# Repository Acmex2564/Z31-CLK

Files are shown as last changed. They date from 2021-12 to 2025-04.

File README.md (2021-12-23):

# Z31-CLK
Replacement clock for Z31

Z31 GL clocks are a a 4-digit VFD driven by a HD44013 MCU. 

For no good reason I intend to replace all parts except the VFD, which uniquely operates directly DC voltage through a couple current limiting resistors and protection diodes. 

Replacement clock will source time from a new TCU design, and communicate over CAN, allowing it to serve as an interface to other accessories I've installed.

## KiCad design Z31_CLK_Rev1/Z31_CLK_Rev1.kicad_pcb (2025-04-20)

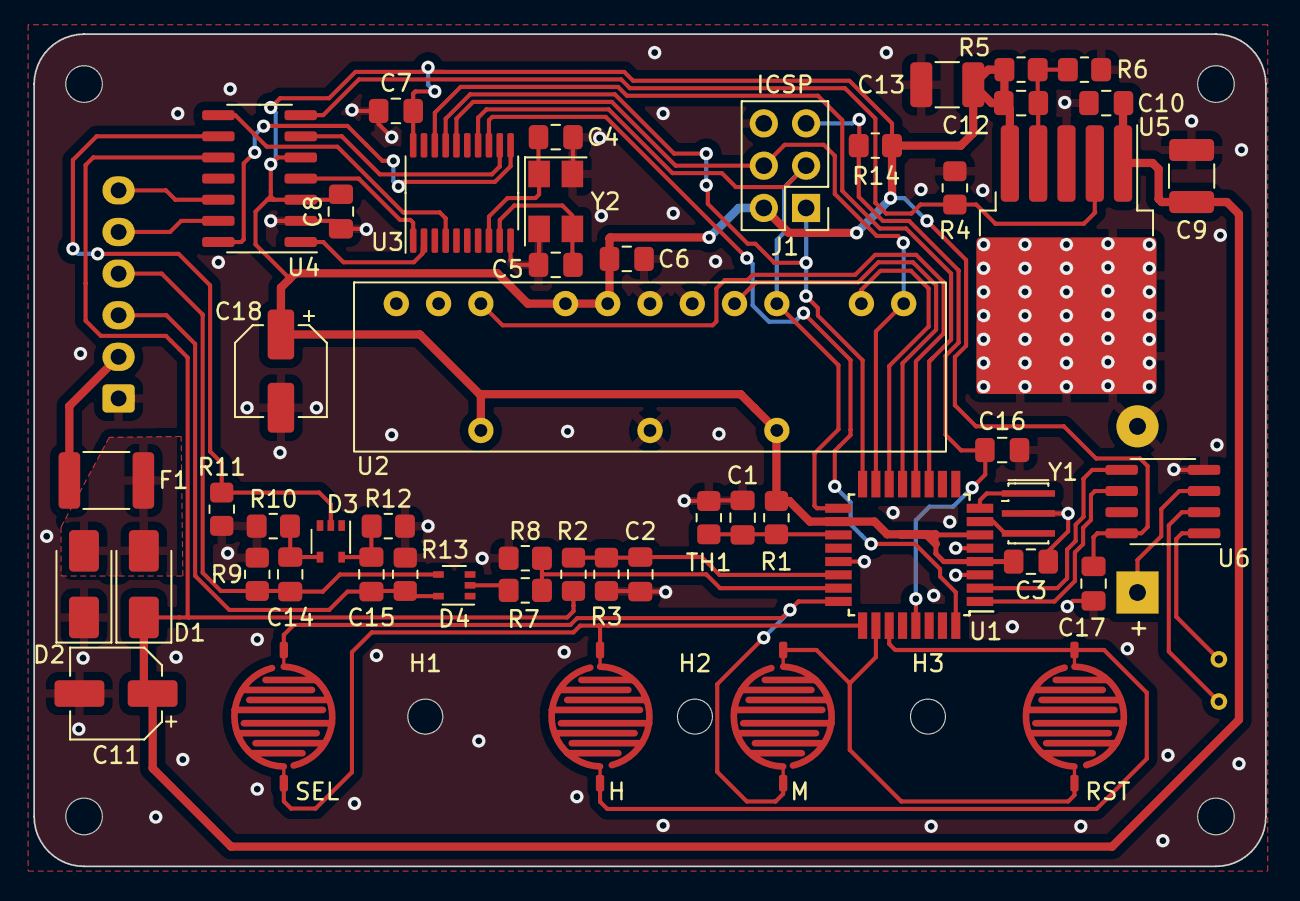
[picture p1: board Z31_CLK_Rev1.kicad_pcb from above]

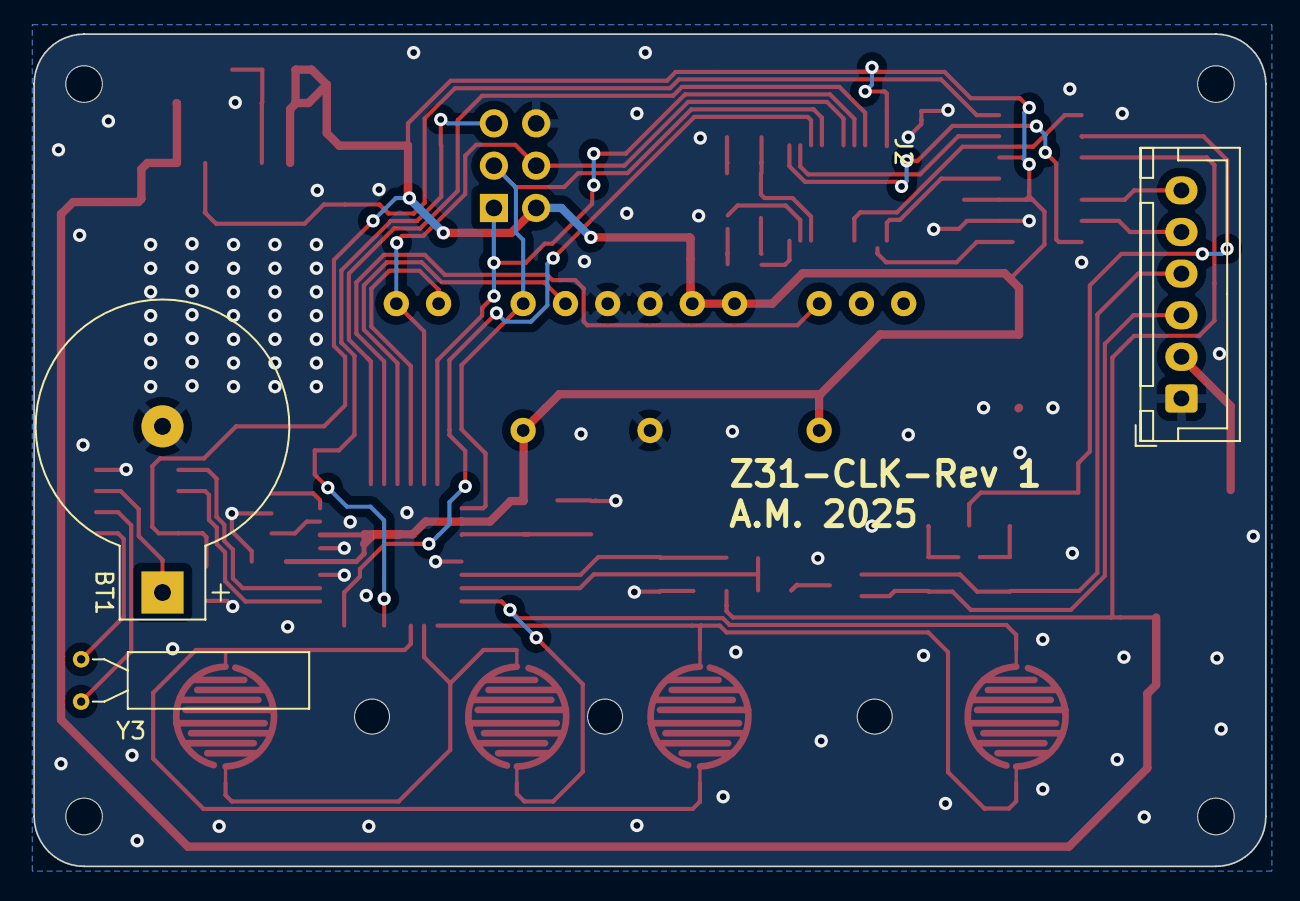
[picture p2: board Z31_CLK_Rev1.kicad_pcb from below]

Board: 2 copper layers, 74.0 x 50.0 mm, 61 parts (3 on the bottom side), 45 nets.

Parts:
BT1: 3V; BatteryHolder_Keystone_500
C1, C2, C6, C7, C8, C10, C16, C17: 100nF; C_0805_2012Metric_Pad1.18x1.45mm_HandSolder
C3, C14, C15: 100n; C_0805_2012Metric_Pad1.18x1.45mm_HandSolder
C4, C5: 10pF; C_0805_2012Metric_Pad1.18x1.45mm_HandSolder
C9: 1u; C_1210_3225Metric_Pad1.33x2.70mm_HandSolder
C11, C18: 22uF; CP_Elec_5x5.7
C12: N/A; C_0805_2012Metric_Pad1.18x1.45mm_HandSolder
C13: yes; C_1210_3225Metric_Pad1.33x2.70mm_HandSolder
D1: D_Schottky; D_SMA
D2: SMAJ18CAQ-13-F; D_SMA
D3, D4: MMBD4448HCQW; SOT-353_SC-70-5
F1: Polyfuse; Fuse_1812_4532Metric_Pad1.30x3.40mm_HandSolder
H1, H2, H3: MountingHole; MountingHole_2.1mm
H4, H5, H6, H7: MountingHole; MountingHole_2.2mm_M2_DIN965
J1: ICSP; PinHeader_2x03_P2.54mm_Vertical
J2: Conn_01x06_Male; JST_XH_B6B-XH-A_1x06_P2.50mm_Vertical
R1: 47K; R_0805_2012Metric_Pad1.20x1.40mm_HandSolder
R2, R3: R; R_0805_2012Metric_Pad1.20x1.40mm_HandSolder
R4, R7, R8, R9, R10, R11, R12, R13, R14: 10k; R_0805_2012Metric_Pad1.20x1.40mm_HandSolder
R5, R6: N/A; R_0805_2012Metric_Pad1.20x1.40mm_HandSolder
SW1: Select; membrane_button
SW2: Hour; membrane_button
SW3: Reset; membrane_button
SW4: Minute; membrane_button
TH1: NTC 47K; R_0805_2012Metric_Pad1.20x1.40mm_HandSolder
U1: ATMEGA328-AURCT-ND; TQFP-32_7x7mm_P0.8mm
U2: HCMS-291x
U3: MCP2515-xST; TSSOP-20_4.4x6.5mm_P0.65mm
U4: TJR1443; SO-14_3.9x8.65mm_P1.27mm
U5: NCV4276B; TO-263-5_TabPin3
U6: DS1307Z+; SOIC-8_3.9x4.9mm_P1.27mm
Y1: 16MHz; Resonator_SMD_Murata_CSTxExxV-3Pin_3.0x1.1mm_HandSoldering
Y2: 8MHz; Crystal_SMD_5032-4Pin_5.0x3.2mm
Y3: 32.768k; Crystal_AT310_D3.0mm_L10.0mm_Horizontal

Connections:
+5V: C3.1, C6.2, C7.2, C8.2, C12.1, C13.1, C17.2, C18.1, J1.2, R1.1, R5.1, R14.1, U1.4 (VCC), U1.6 (VCC), U1.18 (AVCC), U2.3 (V_{LED}), U2.10 (V_{LED}), U2.21 (SEL), U2.22 (V_{Logic}), U3.20 (VDD), U4.3 (Vcc), U4.5 (Vio), U5.5 (OUT), U6.8 (VCC)
+12V: C9.1, C10.1, C11.1, D1.1 (K), R2.1, U4.10 (Vbat), U5.1 (IN)
/+12V_ACC: C14.1, D4.4 (A), J2.4, R9.1
/+12V_CONST: F1.2, J2.2
/CANH: J2.5, U4.13 (CANH)
/CANL: J2.6, U4.12 (CANL)
/CAN_EN: U3.12 (~RX0BF), U4.6 (EN)
/CAN_ERR: U3.4 (~TX0RTS), U4.8 (~ERR)
/CAN_STB: U3.11 (~RX1BF), U4.14 (~STB_N)
/ILLUM: C15.1, D4.5 (A), J2.3, R13.1
/Key_1: SW3.2, SW4.2, U1.26 (PC3)
/Key_2: SW1.1, SW2.1, U1.25 (PC2)
/Key_A: SW1.2, SW3.1, U1.24 (PC1)
/Key_B: SW2.2, SW4.1, U1.27 (PC4)
/MODULE_TEMPERATURE: C1.1, R1.2, TH1.1, U1.19 (ADC6)
/MODULE_VOLTAGE: C2.1, R2.2, R3.1, U1.22 (ADC7)
/RS_DISP: U1.14 (PB2), U2.15 (RS)
/RXCAN: U3.2 (RXCAN), U4.1 (TXCAN)
/TXCAN: U3.1 (TXCAN), U4.4 (RXCAN)
/Wake_Pulse: D3.2 (K), R11.1, U4.9 (WAKE)
/Wake_Sense: R7.2, R8.1, U1.23 (PC0)
/~CS_CAN: U1.11 (PD7), U3.18 (~CS)
/~CS_DISP: U1.13 (PB1), U2.18 (~CE)
/~INH: R4.1, U4.7 (INH), U5.2 (INH)
/~RST_DISP: U1.12 (PB0), U2.24 (~RESET)
CAN_INT: U1.32 (PD2), U3.13 (~INT)
GND: BT1.2 (-), C1.2, C2.2, C3.2, C4.1, C5.1, C6.1, C7.1, C8.1, C9.2, C10.2, C11.2, C13.2, C16.1, C17.1, C18.2, D2.1 (A1), J1.6, J2.1, R3.2, R4.2, R6.2, R8.2, R9.2, R10.2, R11.2, R12.2, R13.2, TH1.2, U1.3 (GND), U1.5 (GND), U1.21 (GND), U2.7 (GND_{LED}), U2.19 (BLANK), U2.20 (GND_{Logic}), U3.10 (VSS), U4.2 (GND), U5.3 (GND), U6.4 (GND), Y1.2, Y2.2, Y2.4
MISO: J1.1, U1.16 (PB4), U3.17 (SO)
MOSI: J1.4, U1.15 (PB3), U2.14 (Data_In), U3.16 (SI)
unnamed: BT1.1 (+), U6.3 (VBAT)
unnamed: D1.2 (A), D2.2 (A2), F1.1
unnamed: C14.2, D3.4 (A), R10.1
unnamed: C15.2, D3.5 (A), R12.1
unnamed: D4.2 (K), R7.1
unnamed: U1.1 (PD3), U6.6 (SCL)
unnamed: U1.2 (PD4), U6.5 (SDA)
unnamed: U1.7 (XTAL1/PB6), Y1.3
unnamed: U1.8 (XTAL2/PB7), Y1.1
unnamed: C5.2, U3.9 (OSC1), Y2.3
unnamed: C4.2, U3.8 (OSC2), Y2.1
unnamed: C12.2, R5.2, R6.1, U5.4 (VA)
unnamed: U6.1 (X1), Y3.2
unnamed: U6.2 (X2), Y3.1
RESET: C16.2, J1.5, R14.2, U1.29 (~RESET/PC6)
SCK: J1.3, U1.17 (PB5), U2.17 (CLK), U3.14 (SCK)

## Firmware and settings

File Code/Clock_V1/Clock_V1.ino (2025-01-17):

#include <LedDisplay.h>
#include <Keypad.h>
#include <TimeLib.h>
#include <ACAN.h>

#define CAN_TX 3
#define CAN_RX 4
#define CAN_EN 1

#define CAN_BITRATE_HS 5*100*1000 //500kbit/s
#define ID_LAMBDA 0x400
#define ID_BRIGHTNESS 0x202
#define ID_TEMPERATURE 0x750
#define ID_STATUS 0x755
#define ID_SPEED 0x760
#define ID_FUEL 0x720

#define ledData 23
#define ledRS 22
#define ledClk 21
#define ledEn 15
#define ledRst 14

#define ledLen 8

#define TIME_HEADER  "T"   // Header tag for serial time sync message

#define PAGE_CLOCK 0 //"HH:MM:SS"
#define PAGE_CAL 1 //"DD/MM/YY"
#define PAGE_AFR 2 //"AFR XXXX"
#define PAGE_LSU_TEMP 3 //"LSU YYYC"
#define PAGE_LSU_STATE 4 //"STA 0xZZ"
#define PAGE_RAD_TEMP 5 //"RAD YY*C"
#define PAGE_FAN_SPD 6 //"FAN XXX%"
#define PAGE_FUEL_AP 7 //
#define PAGE_MAN_AP 8 //
#define PAGE_VEH_SPD 9 //
#define PAGE_FUEL_1 10 //
#define PAGE_FUEL_2 11 //



const byte rows = 2;
const byte cols = 2;

char buttons[rows][cols] = {
  {'S', 'R'},
  {'+', '-'}
};
byte rowPins[rows] = {5, 6};
byte colPins[cols] = {7, 8};

Keypad buttonPad = Keypad(makeKeymap(buttons), rowPins, colPins, rows, cols);

LedDisplay disp = LedDisplay(ledData, ledRS, ledClk, ledEn, ledRst, ledLen);

int brightness = 15;

int currentPage = 0;

int TZ_ADJUST = -4;


uint8_t currentSecond = second();

word lambda;
float afr;
unsigned int temp = 0;
byte lsu_stat;

int tempWater;
int tempAmbient;
int pressManifold;
int pressFuel;
int vehicleSpeed;
int pwmFan;
int fuelMain;
int fuelSub;


unsigned long timeLastLambda;
unsigned long timeLastTemp;
unsigned long timeLastStatus;
unsigned long timeLastSpeed;
unsigned long timeLastFuel;
unsigned long timeMaxMessage = 2000;

void setup() {
  // put your setup code here, to run once:
  Serial.begin(115200);
  //while (!Serial);
  disp.begin();
  disp.setBrightness(brightness);

  pinMode(CAN_TX, OUTPUT);
  pinMode(CAN_EN, OUTPUT);
  pinMode(CAN_RX, INPUT_PULLUP);

  ACANSettings settingsHSCan (CAN_BITRATE_HS);


  settingsHSCan.mRxPinHasInternalPullUp = false;
  settingsHSCan.mTxPinIsOpenCollector = false;
  uint32_t errorCan = ACAN::can0.begin(settingsHSCan);

  if (0 == errorCan) {
    Serial.print("Alive. CAN OK");
  }
  else {
    disp.print("ERR 0x"); disp.print(errorCan, HEX);
    Serial.print("CAN Failure. 0x"); Serial.println(errorCan, HEX);
  }
  setSyncProvider(getTeensy3Time);
  if (timeStatus() != timeSet) {
    Serial.println("Unable to sync with the RTC");
  } else {
    Serial.println("RTC has set the system time");
  }
}


void loop() {
  // put your main code here, to run repeatedly:
  char key = buttonPad.getKey();

  if (key) {
    Serial.println(key);
    updateDisp(currentPage, key);
  }

  if (Serial.available()) {
    time_t t = processSyncMessage();
    if (t != 0) {
      Teensy3Clock.set(t); // set the RTC
      setTime(t);
    }
  }

  if (ACAN::can0.available()) {
    CANMessage frameReceived;
    ACAN::can0.receive (frameReceived);


    switch (frameReceived.id)
    {
      case ID_BRIGHTNESS:
          if (frameReceived.data[0] == 254)
          {
              if (brightness != 15) { brightness = 15; disp.setBrightness(brightness);}
          }
          else 
          {
              if (brightness != map(frameReceived.data[0], 0, 253, 1, 15)) {brightness = map(frameReceived.data[0], 0, 253, 1, 15); disp.setBrightness(brightness);}
          }
          
        break;
      case ID_LAMBDA:
        //per spartan3 manual:
        //Data[0]: Lambda x1000 High Byte
        //Data[1]: Lambda x1000 Low Byte
        //Data[2]: LSU Temp/10
        //Data[3]: Status
        lambda = 0;
        lambda = ((int) frameReceived.data[0] << 8) | frameReceived.data[1];
        afr = ((float)lambda / 1000) * 14.7;
        temp = frameReceived.data[2] * 10;
        lsu_stat = frameReceived.data[3];
        timeLastLambda = millis();
        break;

      case ID_TEMPERATURE:
        tempWater = frameReceived.data[0] - 40;
        tempAmbient = frameReceived.data[1] - 40;
        
        timeLastTemp = millis();
        break;

      case ID_STATUS:

        pwmFan = frameReceived.data[0];
        pressManifold = frameReceived.data[1];
        pressFuel = frameReceived.data[2] * 3;
        
        timeLastStatus = millis();
        break;

      case ID_SPEED:
        vehicleSpeed = frameReceived.data[0];
        timeLastSpeed = millis();
        break;

      case ID_FUEL:
        fuelMain = frameReceived.data[0];
        fuelSub = frameReceived.data[1];
        timeLastFuel = millis();
        break;
    };
  };

refreshDisp(currentPage);

}

void updateDisp(int currentState, char keyPress) {
  switch (keyPress) {
    case 'S':
      if (currentState >= 11) {
        currentPage = 0;
      }
      else {
        currentPage = currentState + 1;
        Serial.println(currentState);
      }
      break;
    case 'R':
      currentPage = 0;
      break;
  }
}

unsigned long processSyncMessage() {
  unsigned long pctime = 0L;
  const unsigned long DEFAULT_TIME = 1357041600; // Jan 1 2013

  if (Serial.find(TIME_HEADER)) {
    pctime = Serial.parseInt();
    return pctime;
    if ( pctime < DEFAULT_TIME) { // check the value is a valid time (greater than Jan 1 2013)
      pctime = 0L; // return 0 to indicate that the time is not valid
    }
  }
  return pctime;
}

void refreshDisp(int currentState) {
  disp.home();
  switch (currentState) {
    case PAGE_CLOCK: //clock
      if (currentSecond != second()) {
        
        disp.print(getTimeStamp());

      }
      break;
    case 1: //calendar
      
      disp.print(getDateStamp());
      break;

    case PAGE_AFR: //lambda
      
      disp.print("AFR:");
      if (millis() - timeLastLambda > timeMaxMessage) {
        disp.print("NDAT");
      }
      else {
        disp.print((float)lambda / 1000 , 2);
      }
      break;
    case PAGE_LSU_TEMP: //lsu temp
      
      disp.print("LSU ");
      if (millis() - timeLastLambda > timeMaxMessage) {
        disp.print("NDAT");
      }
      else {
        disp.print(temp);
        disp.print("C");
      }
      break;
    case PAGE_LSU_STATE: //lsu status
      
      disp.print("STA ");
      if (millis() - timeLastLambda > timeMaxMessage) {
        disp.print("NDAT");
      }
      else {
        disp.print(lsu_stat, HEX);
      }
      break;

    case PAGE_RAD_TEMP: //radiator temperature
      
      disp.print("RCT ");
      if (millis() - timeLastTemp > timeMaxMessage){
        disp.print("NDAT");
      }
      else {
        disp.print(tempWater);
        disp.print("C  ");
      }
      break;

    case PAGE_FAN_SPD:
      disp.print("FAN ");
      if (millis() - timeLastTemp > timeMaxMessage){
        disp.print("NDAT");
      }
      else {
        disp.printf("%3.0f%   ", 100 * (pwmFan/255.0));
      }
      break;
    case PAGE_FUEL_AP: //fuel pressure
      disp.print("FP ");
      if (millis() - timeLastStatus > timeMaxMessage){
        disp.print(" NDAT");
      }
      else {
        disp.printf("%2.1f#   ", pressFuel*3/6.895);
      }
      break;
    case PAGE_MAN_AP: //manifold pressure
      disp.print("MP ");
      if (millis() - timeLastStatus > timeMaxMessage){
        disp.print(" NDAT");
      }
      else {
        disp.printf("%2.1f#   ", pressManifold/6.895);
      }
      break;

    case PAGE_VEH_SPD: //vehicle speed
      disp.print("SPD ");
      if (millis() - timeLastStatus > timeMaxMessage){
        disp.print(" NDAT");
      }
      else {
        disp.print(vehicleSpeed);
        disp.print("k  ");
      }
      break;

    case PAGE_FUEL_1:
      disp.print("MFL ");
      if (millis() - timeLastFuel > timeMaxMessage){
        disp.print("NDAT");
      }
      else {
        disp.printf("%2.1f", ((float)fuelMain)/10);
      }
      break;
    case PAGE_FUEL_2:
      disp.print("SFL ");
      if (millis() - timeLastFuel > timeMaxMessage){
        disp.print("NDAT");
      }
      else {
        disp.printf("%2.1f", ((float)fuelSub)/10);
      }
      break;
  }
}

time_t getTeensy3Time()
{
  return Teensy3Clock.get();
}

String getTimeStamp() {
  char timestamp[8] = "";
  sprintf(timestamp, "%02d:%02d:%02d", hour(now() + 60 * 60 * TZ_ADJUST), minute(now() + 60 * 60 * TZ_ADJUST), second(now() + 60 * 60 * TZ_ADJUST));
  return timestamp;
}

String getDateStamp() {
  char datestamp[8] = "";
  sprintf(datestamp, "%02d-%02d-%02d", day(now() + 60 * 60 * TZ_ADJUST), month(now() + 60 * 60 * TZ_ADJUST), year(now() + 60 * 60 * TZ_ADJUST) % 100);
  return datestamp;
}

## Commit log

2022-05-29 add code
    [Z31_CLK_Rev1.kicad_pcb, Z31_CLK_Rev1.kicad_sch]
2025-01-17 Feature-complete Z31-CLK-Rev1; some PCB layout cleanup may still be useful.
    Review pending.
    [Z31_CLK_Rev1.kicad_pcb, Z31_CLK_Rev1.kicad_sch]
2025-04-20 Finalize clock design
    [Z31_CLK_Rev1.kicad_pcb, Z31_CLK_Rev1.kicad_sch]
